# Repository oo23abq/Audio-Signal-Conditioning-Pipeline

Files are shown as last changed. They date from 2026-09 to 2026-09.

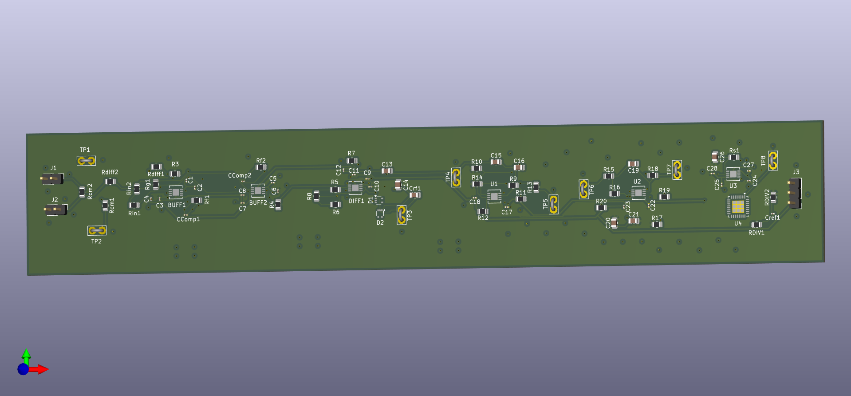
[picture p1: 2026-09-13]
images/pcb/3dpcb.png

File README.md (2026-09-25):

# Precision, Analogue Signal Conditioning Board for ADC Aquisition

**Overview**
* This project implements a complete analogue front-end (AFE) for conditioning audio/sensor signals before digitisation by an AD4695 high‑resolution ADC.
* Simulated and verified in LTspice & designed in KICAD.

The system includes:

* A preamp stage
* A high‑pass filter (HPF)
* A low‑pass filter (LPF)
* A precision VMID bias network
* A fully‑differential ADC driver
* A 3.3 V LDO rail
* ±12 V analog supply rails
* Full hierarchical KiCad schematic design
* LTspice simulation of all analogue blocks

In total, the design uses 36 caps, 33 resistors, 2 silicon diodes, 3 connectors, 15 test points and a selection of 10 ICs. 
*  Total = 99 components  
* The six opamps used were all ADA4084‑2 dual models, chosen for their low noise, high BW, and excellent linearity.

This repository documents the entire engineering workflow, including schematic design, simulation, PCB layout, testing, and future improvements.

System Architecture
  *The signal chain is structured as follows -->
  
1) Preamp Stage
    * Differential microphone/sensor input
    * RF/ESD protection
    * Gain + impedance matching

2) High‑Pass Filter (HPF)
    * Removes DC offset
    * Sets lower cutoff (~15–20 Hz depending on configuration)
    * Biased at VMID

3) Low‑Pass Filter (LPF)
    * Sallen‑Key topology
    * Sets upper cutoff (~15–20 kHz)
    * Unity gain
    * Biased at VMID

4) ADC Driver
    * Fully differential
    * Sets ADC common‑mode
    * Drives AD4695 input stage

5) ADC Interface
    * Reference (4.096 V)
    * LDO (3.3 V)
    * Digital interface pins

6) Power Rails
    * ±12 V analogue rails
    * 3.3 V LDO
    * VMID bias generator
    * Reference buffer

Key Features
  * Hierarchical KiCad design with clean sheet‑to‑sheet signal flow
  * Zero ERC errors (verified)
  * Proper VMID/GND separation
  * Full LTspice simulation of each stage
  * Modular archiecture for easy reuse

Fabricated by JLCPCB.

## Repository Structure

```markdown

```text
├── docs/                                       # General Documentation  
│   └── report/                                 
│       └── sig_conditioning_board_report.docx  # Lab Test Report 
├── gerbers/                                    # Manufacturing Files
│   └── audioafegerbers.zip                     # Production Gerber and drill archives
├── images/                                     # 3D Renders 
│   └── pcb/                                    
│       └── 3dpcb.png                           # Assembled Board 
├── kicad/                                      # Complete KiCad hardware project
│   ├── schematics/                             # Hierarchical Schematics
│   │   ├── signal_conditioning_top.kicad_sch   # Top Level 
│   │   ├── conditioning_input.kicad_sch        # Input Stage
│   │   ├── conditioning_preamp.kicad_sch       # Preamplifier 
│   │   ├── conditioning_highpass.kicad_sch     # High-Pass Filter
│   │   ├── conditioning_lowpass.kicad_sch      # Low-Pass Filter
│   │   ├── conditioning_driver.kicad_sch       # ADC Driver / Buffer
│   │   ├── conditioning_adc.kicad_sch          # ADC Interface
│   │   ├── conditioning_power.kicad_sch        # Power / Rails 
│   │   └── conditioning_testpoints.kicad_sch   # Test Points
│   ├── signal_conditioning_top.kicad_pcb       # PCB Board File 
│   └── signal_conditioning_bom.csv             # Bill of Materials
├── ltspice/                                    # Analogue Simulation 
│   └── waveform.png                            # Transient / Hz Response Plots 
├── LICENSE                                     # MIT License File
└── README.md                                   # Project Guidance / Info

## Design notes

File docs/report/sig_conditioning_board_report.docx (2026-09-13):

Design & Simulation of a Multi-Stage Audio AFE for High-Resolution ADCs

## 1. Abstract

This project implements a precision analogue front-end (AFE) designed to condition low-level differential audio/sensor signals before digitisation by a high-resolution ADC (AD4695 class). The system includes a preamplifier, high-pass filter, low-pass filter, differential ADC driver, and ADC interface, all simulated in LTspice and captured in KiCad using hierarchical design. The goal was to explore real-world analogue design concepts including VMID biasing, differential signalling, filter design, and op-amp selection. 0 ERC was achieved across the entire system.

## 2. Block Diagram

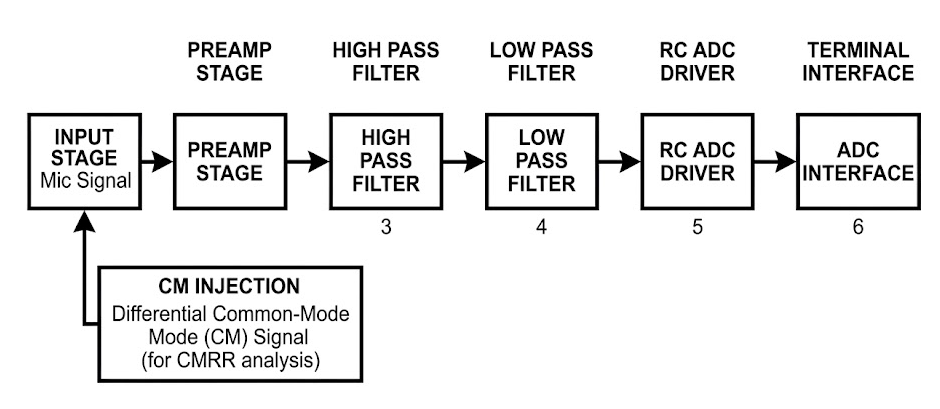
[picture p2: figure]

Figure 1 – System Block Diagram

## 3. Applications

Typically, analogue front ends are used in systems requiring clean, conditioned analogue signals prior to digitisation. Typical applications include:

- Audio acquisition and preamplifiers
- Industrial sensing (strain gauges, accelerometers, pressure sensors)
- Biomedical instrumentation (ECG, EMG, EEG)
- Precision measurement systems and DAQ modules
- Embedded DSP pipelines

This AFE is designed for audio-band acquisition (~15 kHz) and interfaces with AD4695/CS5312-class ADCs, suitable for embedded audio capture and low-noise sensor acquisition.

## 4. Block-Level Design

### 4.1 ADA4084-2 Preamp

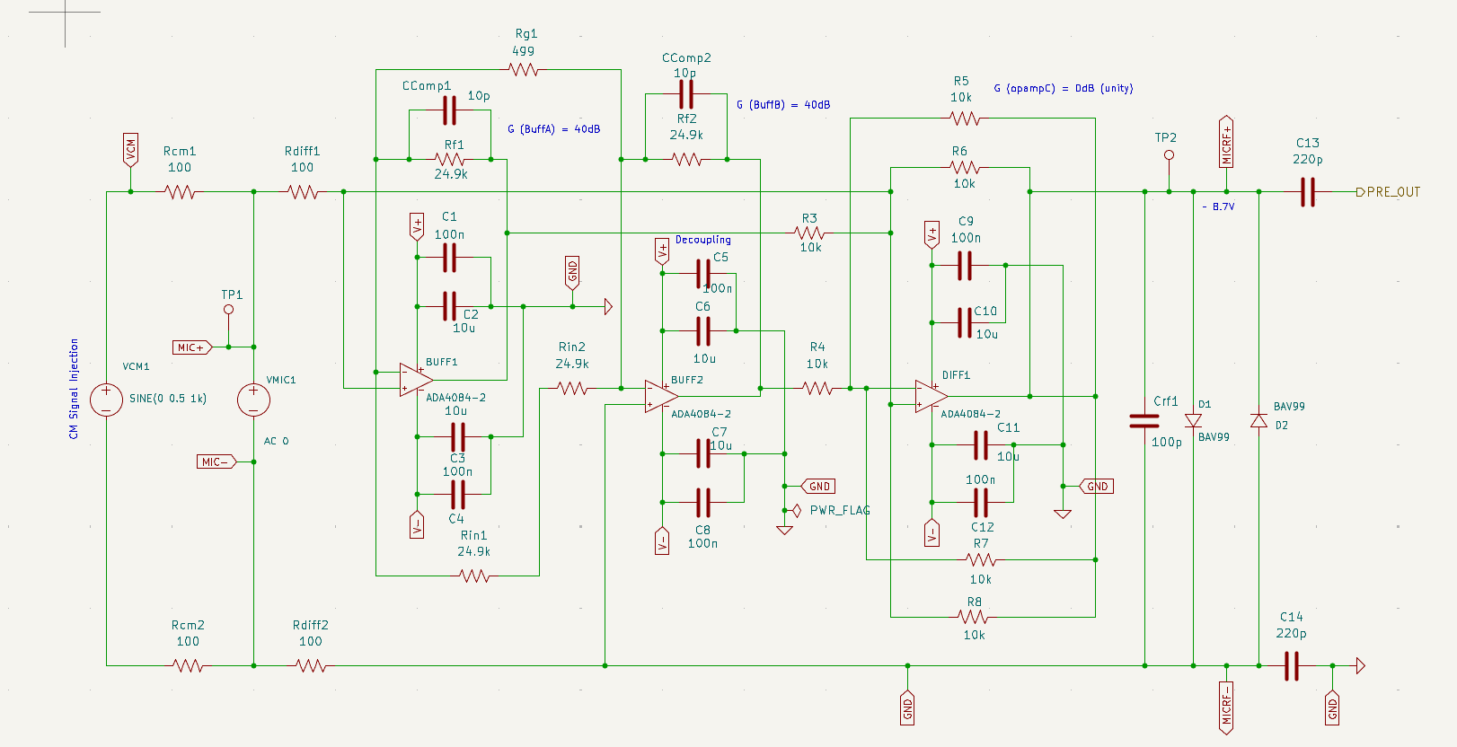
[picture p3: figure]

Figure 2 - Differential microphone input with RF/ESD protection and optional common mode injection source used for evaluating CMRR performance.

Provides initial gain, impedance matching, and RF/ESD protection. Implemented using a discrete three-op-amp instrumentation amplifier topology (see glossary) (INA128/INA163 equivalent) using x3 ADA4084 models.

### 4.2 Power Rails

Generates ±12 V analogue rails and 3.3 V digital rail. Includes decoupling, filtering, and VMID generation.

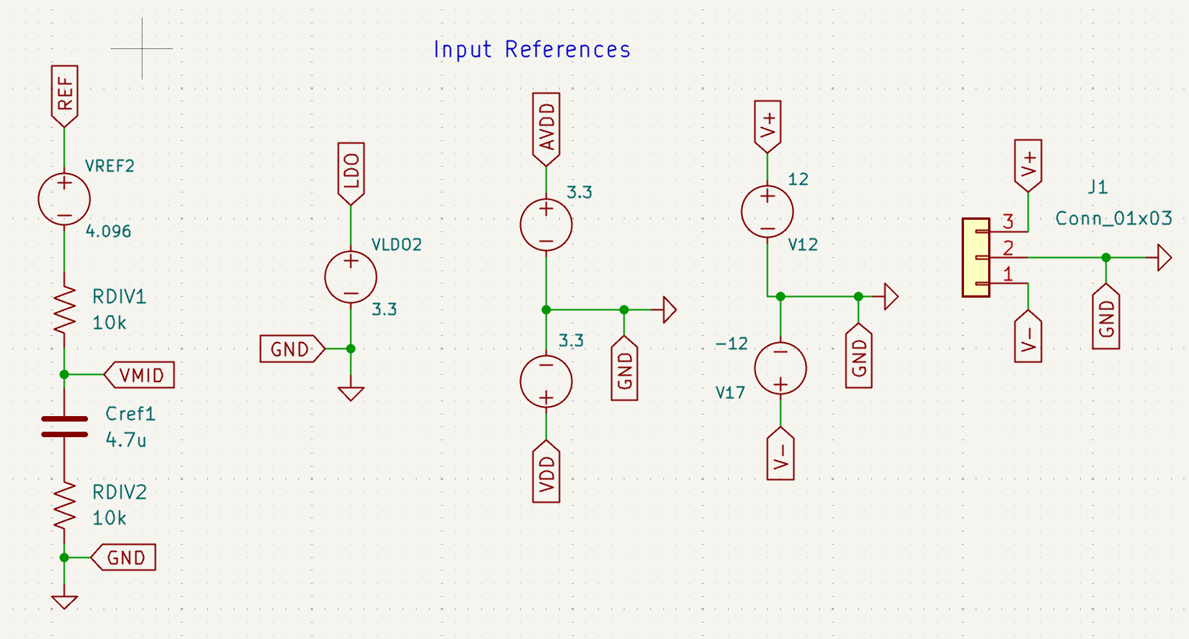
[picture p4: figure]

Figure 8 - ±12 V analogue rails, 3.3 V digital rail, and VMID mid rail generator providing stable biasing for AC coupled stages and differential driver common mode control.

### 4.3 High-Pass Filter

This stage removes DC offset and low-frequency drift from the preamplifier output while preserving signal symmetry. It uses AC-coupling caps biased at VMID to shift the waveform into the ADC’s valid common-mode range. Cut-off Hz is set around 15–20 Hz, ensuring that audio-band content and sensor dynamics remain unaffected while slow baseline wander is eliminated. Both filters employ the Sallen-Key 2nd order topology (see Glossary). See Equations at the end of the report.

The following set the filter cut-off:

- C15
- R9
- R10
- C16

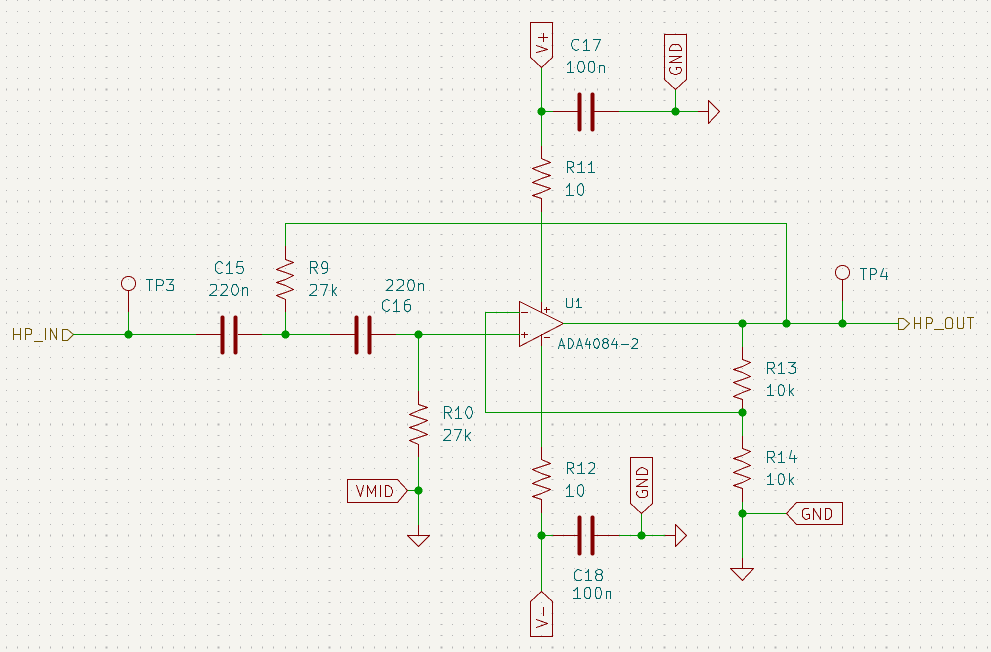
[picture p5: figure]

Figure 4 - AC coupled high pass filter biased at VMID to remove DC offset and low frequency drift while maintaining differential symmetry.

### 4.4 Low-Pass Filter

Following the high pass directly, this defines final analogue bandwidth of the system (~15 kHz). It attenuates high-frequency noise, RF interference, and out-of-band content that could otherwise alias during ADC sampling. Component values were selected to achieve a smooth roll-off and stable Q-factor, ensuring minimal phase distortion within the passband. This stage acts as the primary anti-alias filter, preparing the differential signal for accurate conversion by the ADC driver.

The input is tested at TP5, followed by the below which set the cut-off the filter cut-off:

- R15
- R16
- Equivalent C between C20, C21
- C19

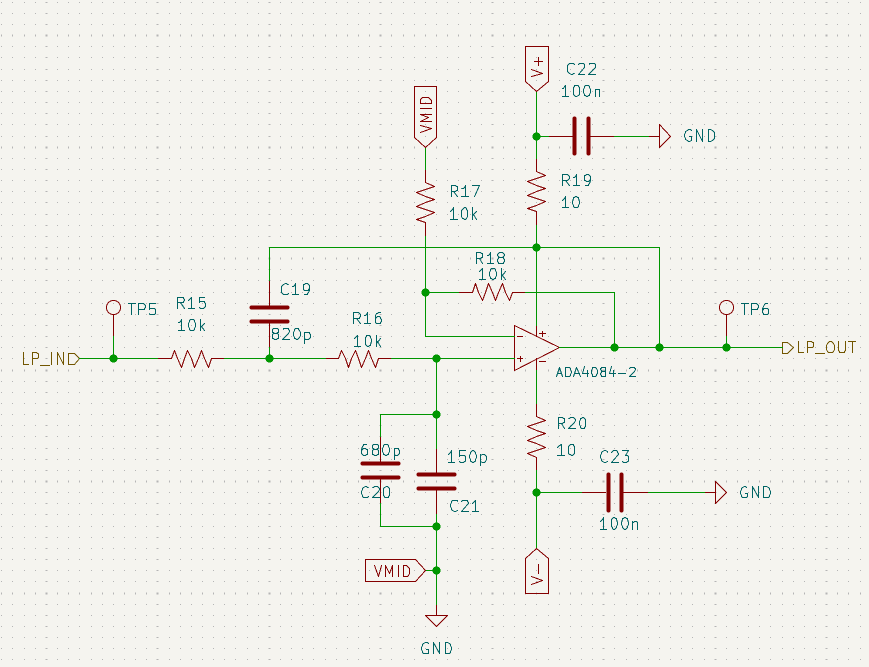
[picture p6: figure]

Figure 5 - Second order Sallen Key low pass filter providing anti-aliasing and defining the final analogue -bandwidth (~15 kHz) before ADC sampling.

### 4.5 ADC Driver

This driver circuit converts the filtered single-ended or pseudo-differential signal into a fully differential output suitable for the AD4695 input structure. Using ADA4084-2 op-amps, it sets the correct differential swing, aligns the common-mode voltage to VMID, and ensures fast settling within the ADC’s acquisition window. The final RC block at the output shapes the transient response and provides impedance matching.

This stage is critical for achieving low distortion, stable common-mode behaviour, and full-scale utilisation of the ADC.

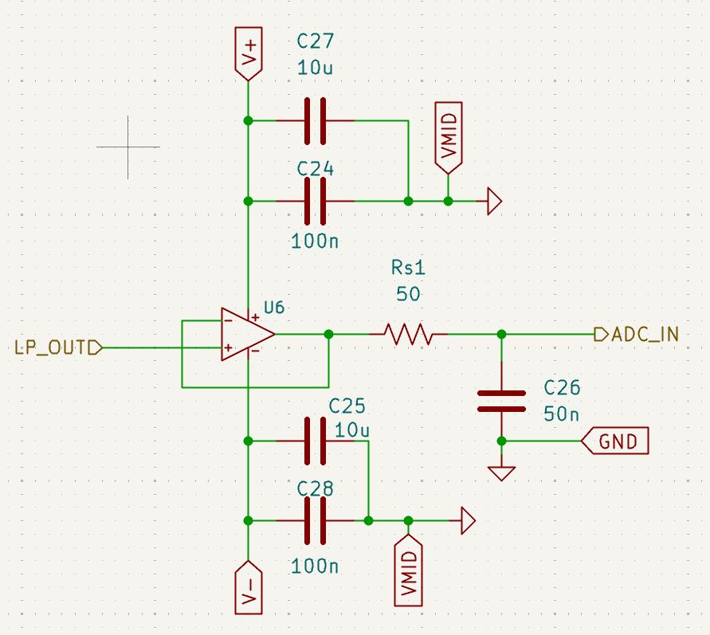
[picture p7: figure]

Figure 6 - Differential ADC driver using ADA4084 2 op amps with RC network for settling control, common mode alignment to VMID, and impedance matching to AD4695 input structure.

### 4.6 ADC Interface

This is the final block, before the audio input is fully digitised. provides the final connection between the analogue signal chain and the AD4695, including reference buffering, decoupling, and a 3.3 V digital supply (datasheet). It ensures that the ADC receives a clean, stable reference voltage and that the differential driver output meets the ADC’s input impedance and common-mode requirements.

This stage also includes terminal pins for SPI or serial data lines, grounding, and local bypass caps placed close to the IC footprint to minimise noise coupling. Together, these elements guarantee reliable sampling and accurate digital conversion.

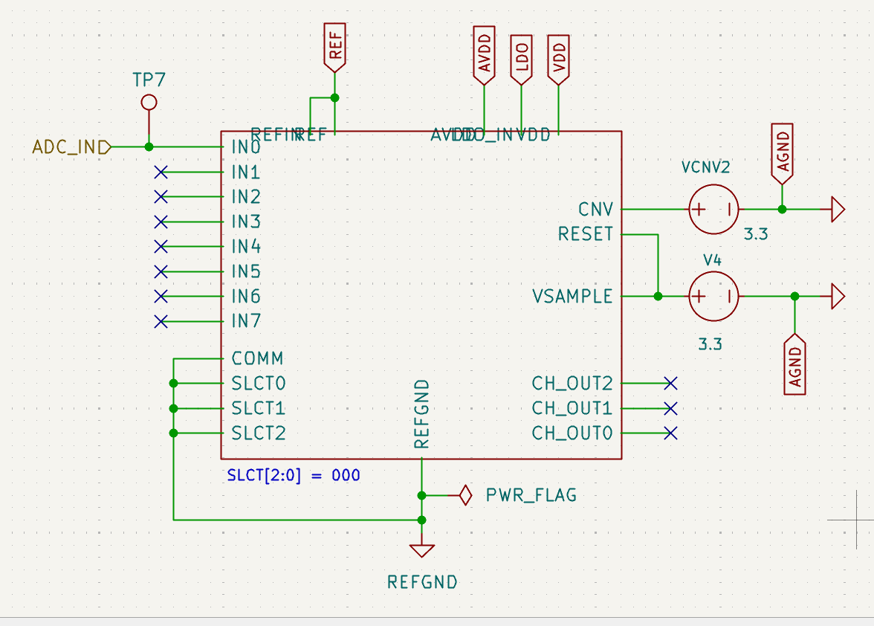
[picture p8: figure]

Figure 7 - Terminal interface for AD4695 including reference buffering, decoupling, 3.3 LDO supply, and digital I/O connectivity.

### 4.7 - Test Points

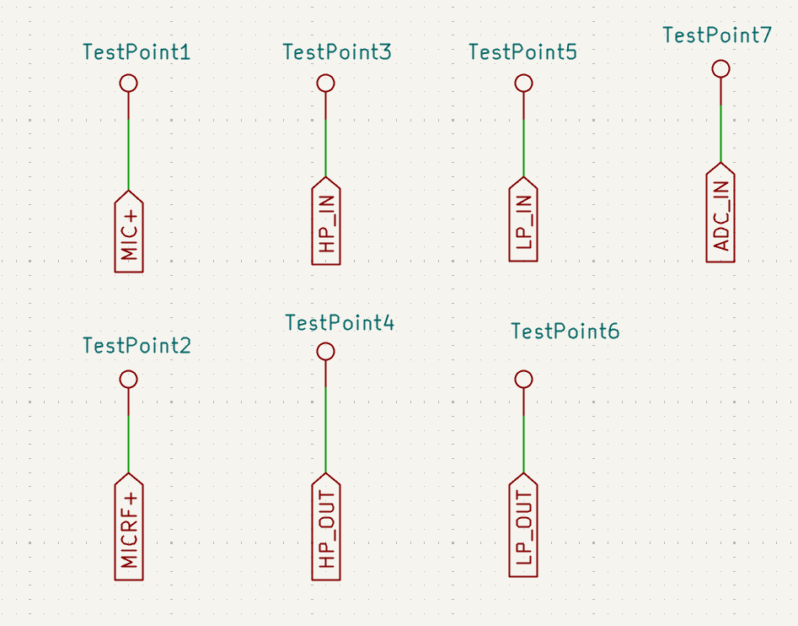
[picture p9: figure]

For the PCB, I’ve decided to probe list of 7 below points across the board to ensure functionality.

- TP1 at MIC+ node
- TP2 at MIC_RF+ node
- TP3 at the high pass filter input
- TP4 at the high pass filter output
- TP5 at the low pass filter input
- TP6 at the low pass filter output
- TP7 at the ADC IN0 input

## 5. Component Choices

Components selected using Octopart, focusing on:

- ADA4084-2 (low noise, high bandwidth)
- AD4695 (high-resolution SAR ADC)
- BAV99 (input protection)
- Precision resistors and film capacitors
- Low-noise 3.3 V LDO

Datasheets and application notes sourced from Analog Devices, TI, and Octopart.

## 6. PCB Considerations

Although PCB layout was not completed, the following considerations were planned:

- Short, symmetric routing for ADC differential inputs
- VMID kept away from digital switching noise
- Tight feedback loops around op-amps
- Decoupling capacitors placed within 2–3 mm of supply pins
- Single analogue ground plane for low-noise operation
- Reference and ADC driver placed close to ADC package

The snapshot below shows the final ERC run, after multiple runs to correct electrical mistakes, whereby the system achieves 0 ERC. Library errors were ignored, as they have 0 impact on functionality. Therefore, my system is layout ready.

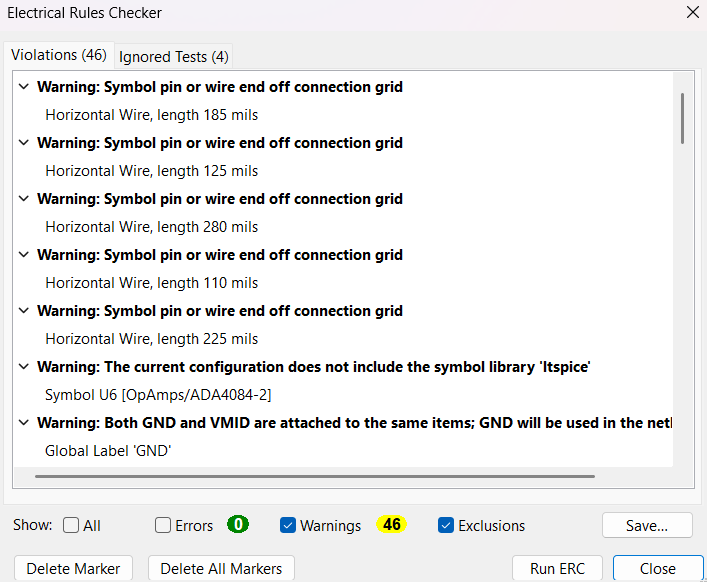
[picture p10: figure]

Figure 12 - KiCad ERC report showing zero electrical errors across all hierarchical sheets, confirming correct net connectivity and schematic integrity.

## 7. Board Design

### 7.1 Schematic Import & Net Preparation

### 7.2 Footprint Selection & Justification

### 7.3 Placement Strategy

### 7.4 Routing Strategy

### 7.5 Power, Ground & VMID Strategy

### 7.6 DRC Validation

### 7.7 Layout and 3D View

## 8. Glossary

A

AC coupling: Using capacitors to block DC components while passing AC signals.

Acquisition Window: Time during which the ADC samples the input; driver must settle within this window.

ADC: analogue-to-digital converter, a device that uses sampling/oversampling techniques to digitise a signal into 0s and 1s.

ADC Driver: A stage that allows us to connect an ADC interface without directly loading a conditioned input.

ADC Interface: The ADC itself, including the pinout, connections, and power ports.

AD4695: A high-speed SAR ADC model used in this project from ADI.

AFE: Analog Front-End; full chain of analogue conditioning blocks.

Alias / Aliasing: Distortion caused when sampling frequency is too low.

Amplifier Saturation: An opamp condition where the output smashes into V+/V- rails

Anti-Alias Filter: A low pass filter placed before the ADC to prevent aliasing.

B

Bandwidth: The range of frequencies in which the system operates.

BAV99: A fast switching, silicon diode model used for protection in this system.

Biasing: Setting the DC op point of a circuit.

Bode Plot: Any graph that shows a frequency response, typically logarithmic.

C

Capacitive Reactance: Opposition to AC by a capacitor: X_C =1/(2πfC) .

CM Injection: Injecting a common-mode signal to test CMRR.

CMRR: Common-Mode Rejection Ratio; ability to reject common-mode noise.

CM Voltage: Average of the two input voltages.

Cutoff Hz: Frequency at which a filter output drops by –3 dB.

D

DAC: Digital-to-Analog Converter (not used in this project). Inverse of ADC

Decoupling Cap: A capacitor placed near IC supply pins to reduce noise/EMI

Differential Pair: Two complementary signal lines carrying + and -

Differential Signal: Signal represented by difference between + and -

Discrete INA: Instrumentation amplifier built using three op-amps.

Driver Settling: The time required for an ADC driver output to reach final value

E

EMI: Electromagnetic interference; unwanted noise from external EM sources.

ESD: Electrostatic discharge; dangerous HV spikes, often protected by diodes.

ERC: Electrical Rule Checker – KiCad feature

Error Budget: Sum of all noise, distortion, and gain errors.

F

Feedback Loop: Path from output to input of op-amp controlling gain and stability.

Filter Order: Number of reactive components determining roll-off steepness.

Full-Scale Range: Maximum differential voltage the ADC can accept.

G

Gain: Ratio of output to input voltages and power.

Gain-Bandwidth Product: Op-amp parameter defining bandwidth at given gain.

Ground Plane: PCB copper area used for low-noise grounding.

H

High-Pass Filter: A filter that passes high Hz, and attenuates low Hz

Hierarchy (KiCad): Organising schematics into multiple sheets.

I

Impedance: AC equivalent of resistance. Can be capacitive or inductive.

INA: Precision differential amplifier with high CMRR, much higher than an opamp.

Input Bias Current: Small DC current flowing into op-amp inputs.

Input Offset Voltage: Small DC voltage error at op-amp input.

L

LSB: Least Significant Bit of ADC resolution.

Low-Pass Filter (LPF): A filter that low high Hz and attenuates high Hz.

LTspice: Simulation tool used for verifying analogue behaviour.

M

Mic Input: Low-level differential audio signal entering the AFE.

MOSFET: Type of 3-pin, field-effect transistor.

N

Noise Floor: The minimum detectable signal level.

Nyquist Frequency: Half the sampling rate.

O

Octopart: Renesas-owned, component search engine used for selecting parts.

Op-Amp: Operational Amplifier, amplifies the difference between inverting, non-inverting pins.

Oversampling: Sampling a higher rate to reduce noise.

P

PCB: Printed Circuit Board

Preamplifier: An early stage in analogue systems to boost low input signals.

PSRR: Power Supply Rejection Ratio (irrelevant for this project).

PWR_FLAG: A KiCad symbol indicating a net is intentionally powered.

Q

Q-factor: A value that defines the overall performance of opamp

R

Time Constant: (tau) τ=RC .

Reference Voltage: Voltage defining ADC full-scale range.

Resistor Divider: Two resistors forming a scaled voltage output. Commonly used in undervoltage lockout, or to turn “on” a chip.

S

Sallen-Key Filter: a 2nd order, active filter topology used to build LPFs, HPFs.

SAR ADC: Successive Approximation Register – type of ADC.

Settling Time: The time required for output to reach final value.

Signal Chain: A sequence of blocks processing the signal.

T

Test Points: Nodes defined on the PCB for probing and power injection.

Thermal Noise: Random noise generated by resistors.

V

Virtual Ground: A ref point treated as 0 V for AC signals.

VMID: Mid-rail bias used for AC-coupled stages.

Z

Zero-Error ERC: When KiCad reports no electrical issues.

## 9. Appendices

### A1 - Key Equations

Input stage & CM injection

Differential & common-mode definition V_(diff) =V_(+) -V_(-)

Common-mode voltage V_(cm) =(V_(+) +V_(-))/2

Reconstructing input terminals from V_(diff) and V_(cm)

V_(+) =V_(cm) +(V_(diff))/2

V_(-) =V_(cm) -(V_(diff))/2

CMRR CMRR=20log_10 ((A_(diff))/(A_(cm)))

Preamp Equations

Three-opamp INA gain G_(INA) =1+(2R)/(R_G)

Output differential voltage of INA V_(out,diff) =G_(INA) ⋅V_(diff,in)

Output common-mode (ideally) V_(out,cm) ≈V_(cm,in)

Filter Equations

Assuming simple RC high-pass or AC-coupling into VMID:

Cut-Off Hz f_(c,LPF) ≈1/(2π√(R_1 R_2 C_1 C_2))

Cut-Off Hz (simplified)

If R1=R2= R_(HPF) and C1=C2= C_(HPF) , the original equation simplified to the below:

f_(c,HPF) =1/(2πR_(HPF) C_(HPF))

The equation is also the same as the cut off Hz formula for a 1st order RC filter.

Q-factor Q≈(√(R_1 R_2 C_1 C_2))/(R_1 C_2 +R_2 C_1)

RC Driver

Differential output of driver V_(ADC,diff) =G_(DRV) ⋅V_(LPF,out,diff)

Common-mode at ADC input V_(ADC,cm) =(V_(ADC+) +V_(ADC-))/2=V_(MID)

RC time constant for driver network τ_(DRV) =R_(DRV) C_(DRV)

Settling behaviour (first-order) V(t)=V_(final) +(V_(initial) -V_(final) )e^(-t/τ_(DRV))

ADC Equations

ADC input range (differential) V_(ADC,diff,max) ≈2V_(ref)

LSB size (for N-bit ADC) LSB=(2V_(ref))/(2^N)

### A2 - Software

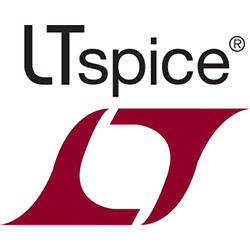
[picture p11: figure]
LTspice | Software | UNLV Information Technology
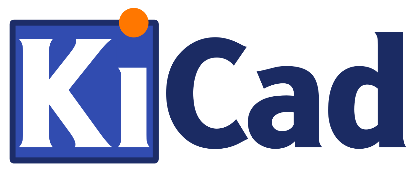
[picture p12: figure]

Software used in this project:

- KiCad
- LTspice
- Octopart

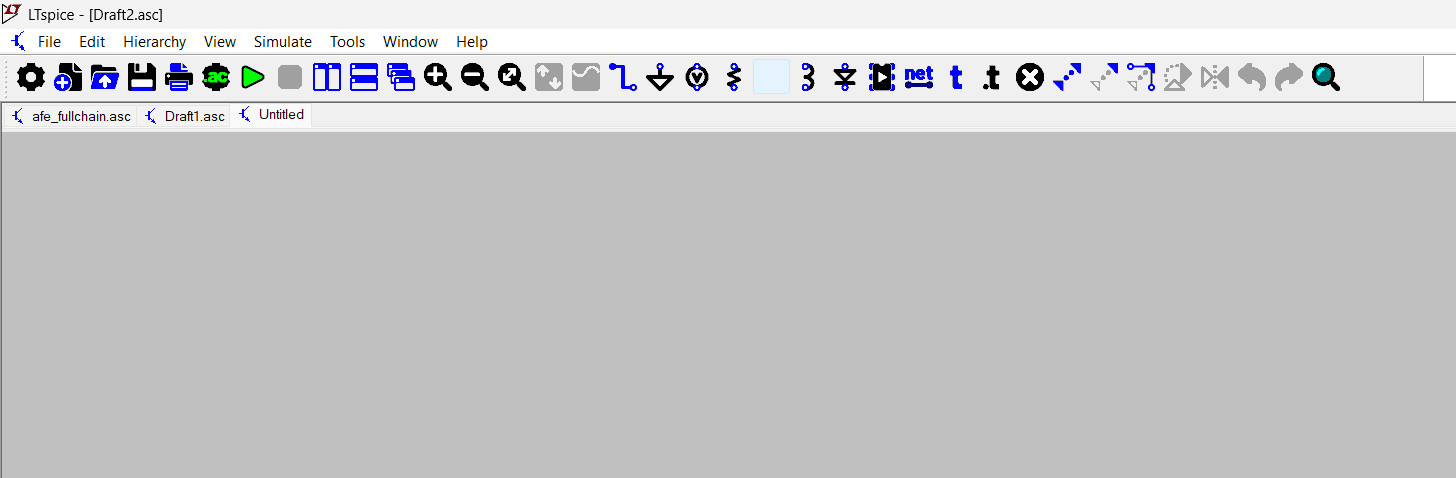
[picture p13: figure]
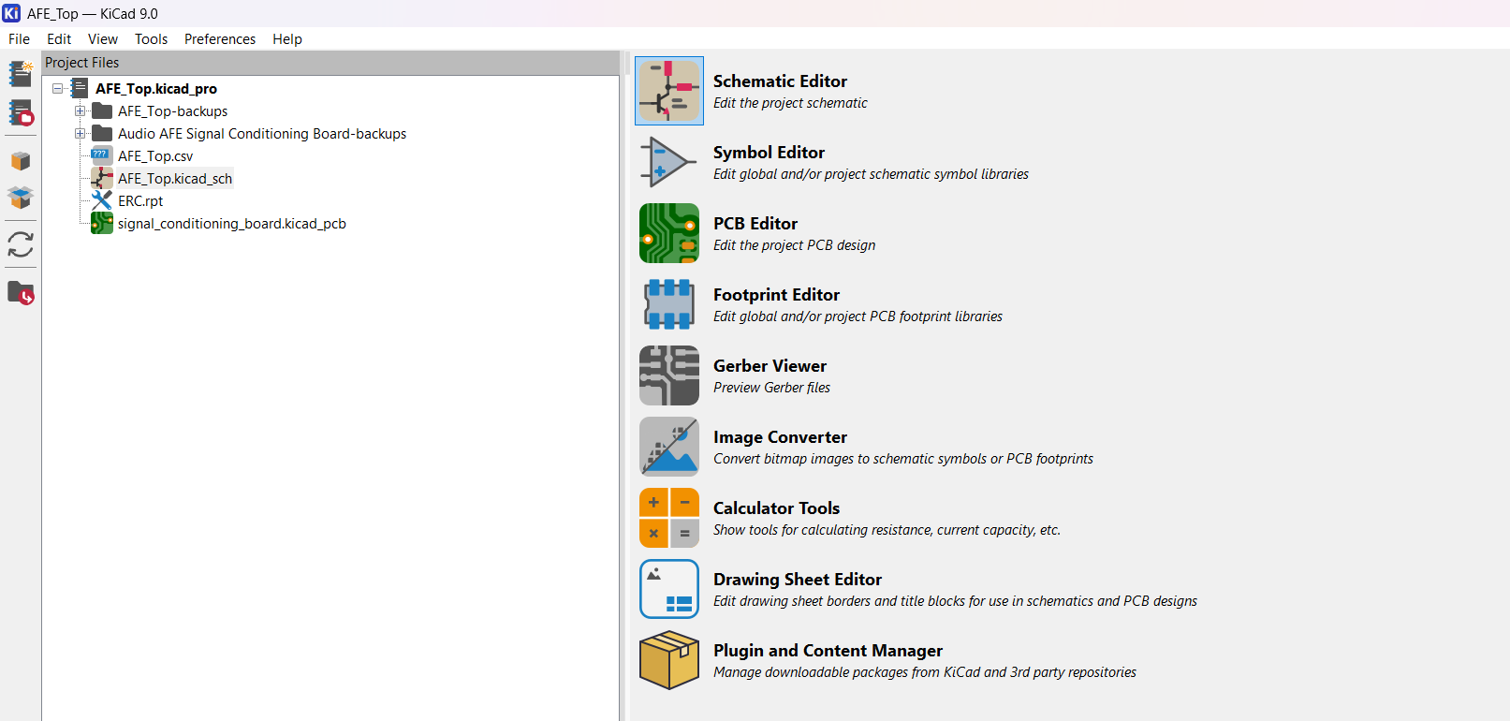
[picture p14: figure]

Omar Othman University of Hertfordshire BEng (Hons) Electrical and Electronic Engineering

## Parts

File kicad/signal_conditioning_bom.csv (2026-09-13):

Reference | Value | Footprint | Datasheet | Description
BUFF1 | ADA4084-2 | Package_SO:SOIC-8_5.3x5.3mm_P1.27mm
BUFF2 | ADA4084-2 | Package_SO:SOIC-8_5.3x5.3mm_P1.27mm
C1 | 100n | Capacitor_SMD:C_0201_0603Metric | ~ | Unpolarized capacitor
C2 | 10u | Capacitor_SMD:C_0201_0603Metric | ~ | Unpolarized capacitor
C3 | 10u | Capacitor_SMD:C_0201_0603Metric | ~ | Unpolarized capacitor
C4 | 100n | Capacitor_SMD:C_0201_0603Metric | ~ | Unpolarized capacitor
C5 | 100n | Capacitor_SMD:C_0201_0603Metric | ~ | Unpolarized capacitor
C6 | 10u | Capacitor_SMD:C_0201_0603Metric | ~ | Unpolarized capacitor
C7 | 10u | Capacitor_SMD:C_0201_0603Metric | ~ | Unpolarized capacitor
C8 | 100n | Capacitor_SMD:C_0201_0603Metric | ~ | Unpolarized capacitor
C9 | 100n | Capacitor_SMD:C_0201_0603Metric | ~ | Unpolarized capacitor
C10 | 10u | Capacitor_SMD:C_0201_0603Metric | ~ | Unpolarized capacitor
C11 | 10u | Capacitor_SMD:C_0201_0603Metric | ~ | Unpolarized capacitor
C12 | 100n | Capacitor_SMD:C_0201_0603Metric | ~ | Unpolarized capacitor
C13 | 220p | Capacitor_SMD:C_0805_2012Metric | ~ | Unpolarized capacitor
C14 | 220p | Capacitor_SMD:C_0805_2012Metric | ~ | Unpolarized capacitor
C15 | 220n | Capacitor_SMD:C_0805_2012Metric | ~ | Unpolarized capacitor
C16 | 220n | Capacitor_SMD:C_0805_2012Metric | ~ | Unpolarized capacitor
C17 | 100n | Capacitor_SMD:C_0201_0603Metric | ~ | Unpolarized capacitor
C18 | 100n | Capacitor_SMD:C_0201_0603Metric | ~ | Unpolarized capacitor
C19 | 820p | Capacitor_SMD:C_0805_2012Metric | ~ | Unpolarized capacitor
C20 | 680p | Capacitor_SMD:C_0805_2012Metric | ~ | Unpolarized capacitor
C21 | 150p | Capacitor_SMD:C_0805_2012Metric | ~ | Unpolarized capacitor
C22 | 100n | Capacitor_SMD:C_0201_0603Metric | ~ | Unpolarized capacitor
C23 | 100n | Capacitor_SMD:C_0201_0603Metric | ~ | Unpolarized capacitor
C24 | 100n | Capacitor_SMD:C_0201_0603Metric | ~ | Unpolarized capacitor
C25 | 10u | Capacitor_SMD:C_0201_0603Metric | ~ | Unpolarized capacitor
C26 | 50n | Capacitor_SMD:C_0805_2012Metric | ~ | Unpolarized capacitor
C27 | 10u | Capacitor_SMD:C_0201_0603Metric | ~ | Unpolarized capacitor
C28 | 100n | Capacitor_SMD:C_0201_0603Metric | ~ | Unpolarized capacitor
CComp1 | 10p | Capacitor_SMD:C_0201_0603Metric | ~ | Unpolarized capacitor
CComp2 | 10p | Capacitor_SMD:C_0201_0603Metric | ~ | Unpolarized capacitor
Cref1 | 4.7u | Capacitor_SMD:C_0201_0603Metric | ~ | Unpolarized capacitor
Crf1 | 100p | Capacitor_SMD:C_0805_2012Metric | ~ | Unpolarized capacitor
D1 | BAV99 | Package_TO_SOT_SMD:Diodes_SOT-553
D2 | BAV99 | Package_TO_SOT_SMD:Diodes_SOT-553
DIFF1 | ADA4084-2 | Package_SO:SOIC-8_5.3x5.3mm_P1.27mm
J1 | VCM | Connector_PinHeader_2.54mm:PinHeader_1x02_P2.54mm_Vertical | ~ | Generic connector, single row, 01x02, script generated (kicad-library-utils/schlib/autogen/connector/)
J2 | VMIC | Connector_PinHeader_2.54mm:PinHeader_1x02_P2.54mm_Vertical | ~ | Generic connector, single row, 01x02, script generated (kicad-library-utils/schlib/autogen/connector/)
J3 | Conn_01x03 | Connector_PinHeader_2.54mm:PinHeader_1x03_P2.54mm_Vertical | ~ | Generic connector, single row, 01x03, script generated (kicad-library-utils/schlib/autogen/connector/)
R3 | 10k | Resistor_SMD:R_0805_2012Metric | ~ | Resistor, US symbol
R4 | 10k | Resistor_SMD:R_0805_2012Metric | ~ | Resistor, US symbol
R5 | 10k | Resistor_SMD:R_0805_2012Metric | ~ | Resistor, US symbol
R6 | 10k | Resistor_SMD:R_0805_2012Metric | ~ | Resistor, US symbol
R7 | 10k | Resistor_SMD:R_0805_2012Metric | ~ | Resistor, US symbol
R8 | 10k | Resistor_SMD:R_0805_2012Metric | ~ | Resistor, US symbol
R9 | 27k | Resistor_SMD:R_0805_2012Metric | ~ | Resistor, US symbol
R10 | 27k | Resistor_SMD:R_0805_2012Metric | ~ | Resistor, US symbol
R11 | 10 | Resistor_SMD:R_0805_2012Metric | ~ | Resistor, US symbol
R12 | 10 | Resistor_SMD:R_0805_2012Metric | ~ | Resistor, US symbol
R13 | 10k | Resistor_SMD:R_0805_2012Metric | ~ | Resistor, US symbol
R14 | 10k | Resistor_SMD:R_0805_2012Metric | ~ | Resistor, US symbol
R15 | 10k | Resistor_SMD:R_0805_2012Metric | ~ | Resistor, US symbol
R16 | 10k | Resistor_SMD:R_0805_2012Metric | ~ | Resistor, US symbol
R17 | 10k | Resistor_SMD:R_0805_2012Metric | ~ | Resistor, US symbol
R18 | 10k | Resistor_SMD:R_0805_2012Metric | ~ | Resistor, US symbol
R19 | 10 | Resistor_SMD:R_0805_2012Metric | ~ | Resistor, US symbol
R20 | 10 | Resistor_SMD:R_0805_2012Metric | ~ | Resistor, US symbol
Rcm1 | 100 | Resistor_SMD:R_0805_2012Metric | ~ | Resistor, US symbol
Rcm2 | 100 | Resistor_SMD:R_0805_2012Metric | ~ | Resistor, US symbol
Rdiff1 | 100 | Resistor_SMD:R_0805_2012Metric | ~ | Resistor, US symbol
Rdiff2 | 100 | Resistor_SMD:R_0805_2012Metric | ~ | Resistor, US symbol
RDIV1 | 10k | Resistor_SMD:R_0805_2012Metric | ~ | Resistor, US symbol
RDIV2 | 10k | Resistor_SMD:R_0805_2012Metric | ~ | Resistor, US symbol
Rf1 | 24.9k | Resistor_SMD:R_0805_2012Metric | ~ | Resistor, US symbol
Rf2 | 24.9k | Resistor_SMD:R_0805_2012Metric | ~ | Resistor, US symbol
Rg1 | 499 | Resistor_SMD:R_0805_2012Metric | ~ | Resistor, US symbol
Rin1 | 24.9k | Resistor_SMD:R_0805_2012Metric | ~ | Resistor, US symbol
Rin2 | 24.9k | Resistor_SMD:R_0805_2012Metric | ~ | Resistor, US symbol
Rs1 | 50 | Resistor_SMD:R_0805_2012Metric | ~ | Resistor, US symbol
TestPoint1 | TestPoint |  | ~ | test point
TestPoint2 | TestPoint |  | ~ | test point
TestPoint3 | TestPoint |  | ~ | test point
TestPoint4 | TestPoint |  | ~ | test point
TestPoint5 | TestPoint |  | ~ | test point
TestPoint6 | TestPoint |  | ~ | test point
TestPoint7 | TestPoint |  | ~ | test point
TP1 | TestPoint | TestPoint:TestPoint_Bridge_Pitch2.54mm_Drill1.0mm | ~ | test point
TP2 | TestPoint | TestPoint:TestPoint_Bridge_Pitch2.54mm_Drill1.0mm | ~ | test point
TP3 | TestPoint | TestPoint:TestPoint_Bridge_Pitch2.54mm_Drill1.0mm | ~ | test point
TP4 | TestPoint | TestPoint:TestPoint_Bridge_Pitch2.54mm_Drill1.0mm | ~ | test point
TP5 | TestPoint | TestPoint:TestPoint_Bridge_Pitch2.54mm_Drill1.0mm | ~ | test point
TP6 | ~ | TestPoint:TestPoint_Bridge_Pitch2.54mm_Drill1.0mm | ~ | test point
TP7 | ~ | TestPoint:TestPoint_Bridge_Pitch2.54mm_Drill1.0mm | ~ | test point
TP8 | TestPoint | TestPoint:TestPoint_Bridge_Pitch2.54mm_Drill1.0mm | ~ | test point
U1 | ADA4084-2 | Package_SO:SOIC-8_5.3x5.3mm_P1.27mm
U4 | ADA4084-2 | Package_SO:SOIC-8_5.3x5.3mm_P1.27mm
U6 | ADA4084-2 | Package_SO:SOIC-8_5.3x5.3mm_P1.27mm
U11 | AD4695 | Package_CSP:LFCSP-32-1EP_5x5mm_P0.5mm_EP3.1x3.1mm
V-2 | 3.3
V4 | 3.3
V7 | 3.3
V12 | 12
V17 | -12
VCNV2 | 3.3
VLDO2 | 3.3
VREF2 | 4.096

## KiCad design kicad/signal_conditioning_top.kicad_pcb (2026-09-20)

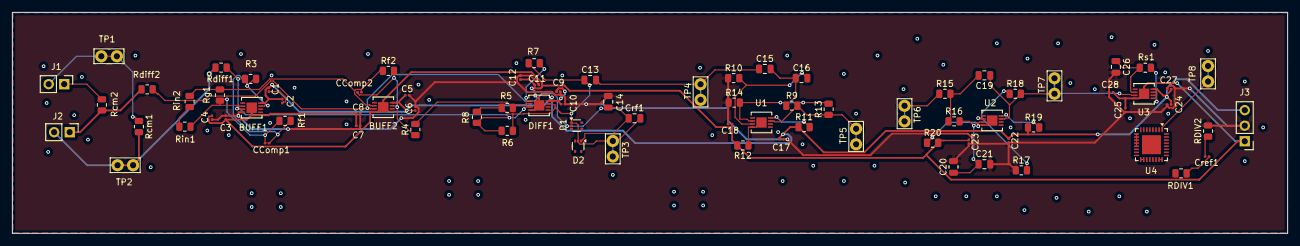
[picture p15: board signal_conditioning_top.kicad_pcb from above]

Board: 2 copper layers, 208.3 x 36.1 mm, 82 parts (0 on the bottom side), 39 nets.

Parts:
BUFF1, BUFF2: ADA4084-2ACPZ-R7; CP_8_12_ADI
C1, C4, C5, C8, C9, C12, C17, C18, C22, C23, C24, C28: 100n; C_0201_0603Metric
C2, C3, C6, C7, C10, C11, C25, C27: 10u; C_0201_0603Metric
C13, C14: 220p; C_0805_2012Metric
C15, C16: 220n; C_0805_2012Metric
C19: 820p; C_0805_2012Metric
C20: 680p; C_0805_2012Metric
C21: 150p; C_0805_2012Metric
C26: 50n; C_0805_2012Metric
CComp1, CComp2: 10p; C_0201_0603Metric
Cref1: 4.7u; C_0201_0603Metric
Crf1: 100p; C_0805_2012Metric
D1, D2: BAV99; Diodes_SOT-553
DIFF1: ADA4084-2ACPZ-R7; CP_8_12_ADI
J1: VCM; PinHeader_1x02_P2.54mm_Vertical
J2: VMIC; PinHeader_1x02_P2.54mm_Vertical
J3: Conn_01x03; PinHeader_1x03_P2.54mm_Vertical
R3, R4, R5, R6, R7, R8, R13, R14, R15, R16, R17, R18: 10k; R_0805_2012Metric
R9, R10: 27k; R_0805_2012Metric
R11, R12, R19, R20: 10; R_0805_2012Metric
RDIV1, RDIV2: 10k; R_0805_2012Metric
Rcm1, Rcm2: 100; R_0805_2012Metric
Rdiff1, Rdiff2: 100; R_0805_2012Metric
Rf1, Rf2: 24.9k; R_0805_2012Metric
Rg1: 499; R_0805_2012Metric
Rin1, Rin2: 24.9k; R_0805_2012Metric
Rs1: 50; R_0805_2012Metric
TP1, TP2, TP3, TP8: TestPoint; TestPoint_Bridge_Pitch2.54mm_Drill1.0mm
TP4, TP5, TP6, TP7: TestPoint_Bridge_Pitch2.54mm_Drill1.0mm
U1, U2, U3: ADA4084-2ACPZ-R7; CP_8_12_ADI
U4: AD4695; LFCSP-32-1EP_5x5mm_P0.5mm_EP3.1x3.1mm

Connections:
/ADC Driver/ADC_IN: C26.1, Rs1.2, U3.2 (INA-)
/ADC Driver/LP_OUT: C19.1, R18.2, TP7.1, U2.7 (OUTB), U3.3 (INA+)
/ADC Interface/LP_OUT: TP8.1, U4.1 (IN0)
/HPF/HP_IN: C13.2, C15.1, TP4.1
/HPF/HP_OUT: R9.2, R13.1, TP5.1, U1.7 (OUTB)
/LPF/HP_OUT: R15.1, TP6.1
AGND: BUFF1.4 (V-), C3.1, C4.1, C5.2, C6.2, C7.2, C8.2, C9.1, C10.1, C11.2, C12.2, C14.2, C17.2, C18.2, C20.2, C21.2, C22.2, C23.2, C24.2, C25.2, C26.2, C27.2, C28.2, J3.2, R10.1, R14.1, R17.1, RDIV2.2
CM+: J1.2, Rcm1.1, TP1.1
CM-: J1.1, Rcm2.1
GND: Cref1.1, RDIV1.2
MIC+: J2.2, Rcm1.2, Rdiff1.1, TP2.1
MIC-: J2.1, Rcm2.2, Rdiff2.1
MICRF+: C13.1, Crf1.2, D1.1, D2.2, DIFF1.7 (OUTB), R5.2, R6.2, R7.2, R8.2, TP3.1
MICRF-: BUFF2.3 (INA+), C14.1, Crf1.1, D1.2, D2.1, Rdiff2.2
unnamed: BUFF1.3 (INA+), DIFF1.3 (INA+), R3.2, R6.1, R8.1, Rdiff1.2
unnamed: BUFF1.2 (INA-), CComp1.1, Rf1.1, Rg1.1, Rin1.2
unnamed: BUFF1.7 (OUTB), CComp1.2, R3.1, Rf1.2
unnamed: BUFF2.2 (INA-), CComp2.1, Rf2.1, Rg1.2, Rin2.1
unnamed: BUFF2.7 (OUTB), CComp2.2, R4.1, Rf2.2
unnamed: C1.2, C2.2
unnamed: C15.2, C16.1, R9.1
unnamed: C19.2, R15.2, R16.1
unnamed: Cref1.2, RDIV2.1
unnamed: DIFF1.2 (INA-), R4.2, R5.1, R7.1
unnamed: Rin1.1, Rin2.2
unnamed: R12.1, U1.4 (V-), U1.HTAB (EPAD)
unnamed: C16.2, R10.2, U1.3 (INA+)
unnamed: R13.2, R14.2, U1.2 (INA-)
unnamed: R11.2, U1.8 (V+)
unnamed: R20.1, U2.4 (V-), U2.HTAB (EPAD)
unnamed: C20.1, C21.1, R16.2, U2.3 (INA+)
unnamed: R17.2, R18.1, U2.2 (INA-)
unnamed: R19.2, U2.8 (V+)
unnamed: Rs1.1, U3.7 (OUTB)
unnamed: U4.17 (VSAMPLE), U4.18 (RESET)
REF: U4.23 (REF), U4.24 (REFIN)
REFGND: U4.9 (COMM), U4.10 (SLCT0), U4.11 (SLCT1), U4.12 (SLCT2), U4.13 (REFGND)
V+: BUFF1.8 (V+), BUFF2.8 (V+), C1.1, C2.1, C5.1, C6.1, C9.2, C10.2, C17.1, C22.1, C24.1, C27.1, DIFF1.8 (V+), J3.3, R11.1, R19.1, U3.8 (V+)
V-: BUFF1.HTAB (EPAD), BUFF2.4 (V-), BUFF2.HTAB (EPAD), C3.2, C4.2, C7.1, C8.1, C11.1, C12.1, C18.1, C23.1, C25.1, C28.1, DIFF1.4 (V-), DIFF1.HTAB (EPAD), J3.1, R12.2, R20.2, U3.4 (V-), U3.HTAB (EPAD)

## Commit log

2026-09-13 Create kicad
2026-09-13 Create pcb
2026-09-13 Create schematics
